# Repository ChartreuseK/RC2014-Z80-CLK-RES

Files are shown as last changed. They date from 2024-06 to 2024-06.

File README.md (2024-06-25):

## A z80 + Clock + Reset Board for the RC2014 Bus
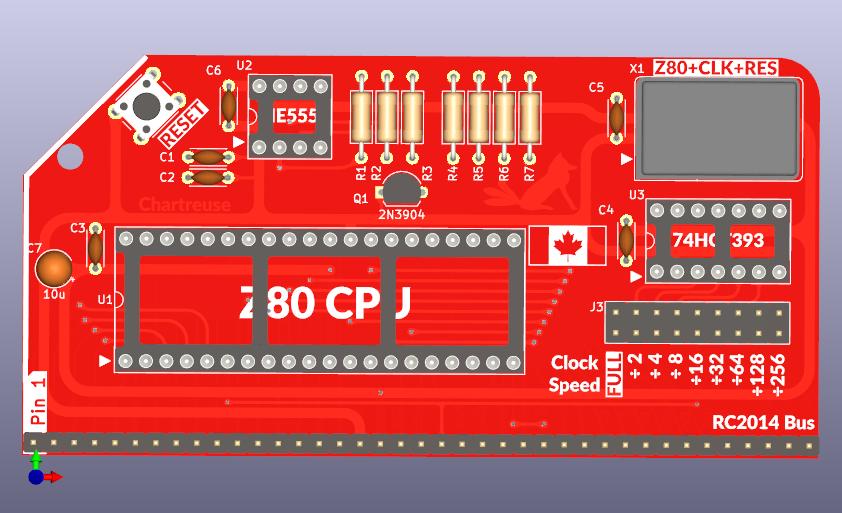
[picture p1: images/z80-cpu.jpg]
Revision 1 board front


A simple z80 board with integrated clock circuit (can oscillator) and divider. A 555 timer circuit provides power on and on demand reset with a clean pulse. 

The 74HCT393 is optional if you don't wish to divide the clock, just add a jumper or link on the FULL speed pad below it and it'll not be used. There is a shared footprint for either DIP-14 or DIP-8 can oscillators. For DIP-8 align it to the right edge of the socket. The reset pulse length can be shortened by lowering the values of R1 and R2, or adjusting the capacitor values. The 10k value of the pullup resistors is also nominal, and will likely work fine from 1k to 10k

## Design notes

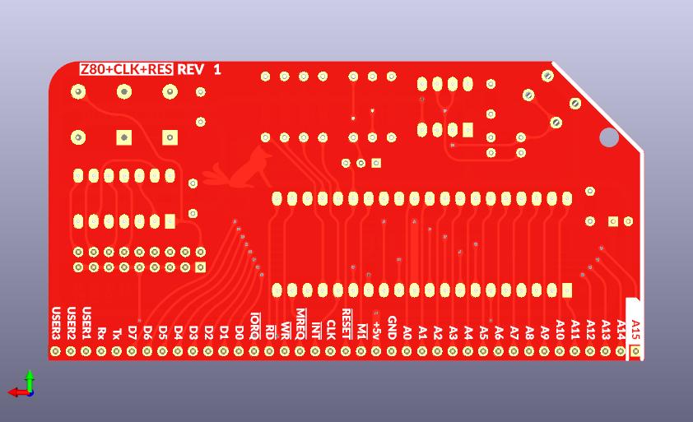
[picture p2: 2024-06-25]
images/z80-cpu-back.jpg

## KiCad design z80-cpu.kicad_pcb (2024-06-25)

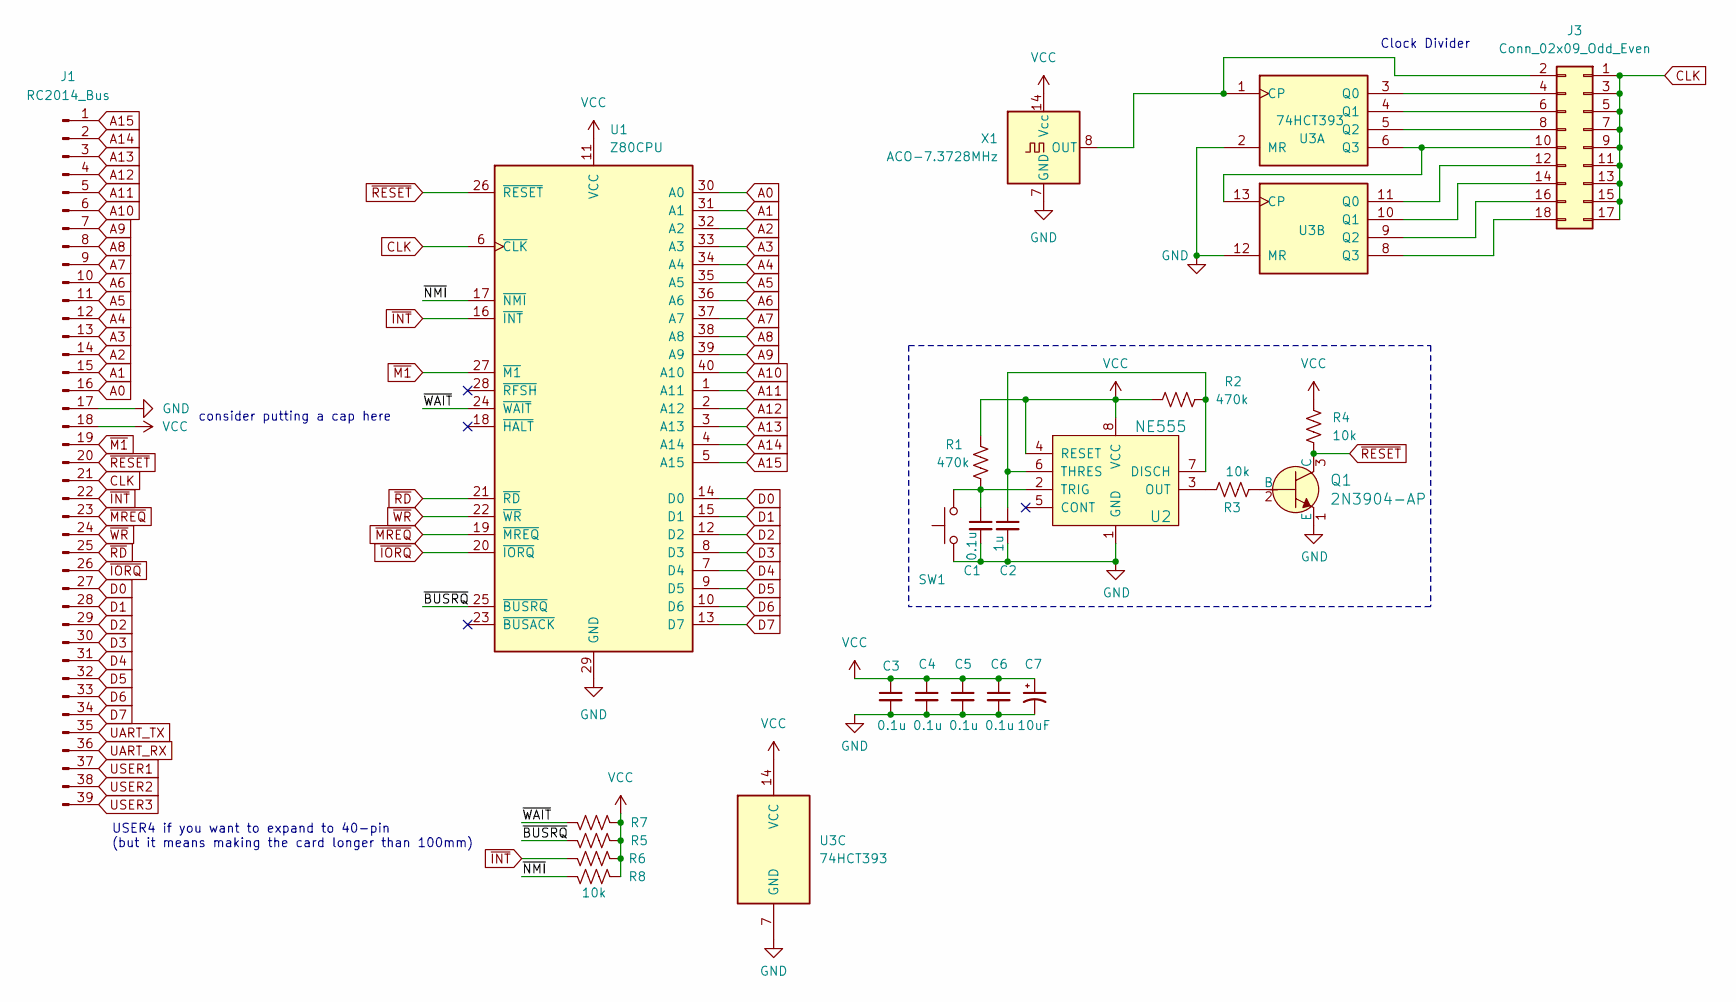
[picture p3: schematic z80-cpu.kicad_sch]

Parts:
C1, C3, C4, C5, C6: 0.1u; C_Disc_D4.3mm_W1.9mm_P5.00mm
C2: 1u; C_Disc_D4.3mm_W1.9mm_P5.00mm
C7: 10uF; CP_Radial_Tantal_D4.5mm_P2.50mm
J1: RC2014_Bus; PinHeader_1x39_P2.54mm_Vertical
J3: Conn_02x09_Odd_Even; PinHeader_2x09_P2.54mm_Vertical
Q1: 2N3904-AP; TO-92L_Inline_Wide; MPN 2N3904-AP; Digi-Key_PN 2N3904-APCT-ND
R1, R2: 470k; R_Axial_DIN0207_L6.3mm_D2.5mm_P10.16mm_Horizontal
R3, R4, R5, R6, R7, R8: 10k; R_Axial_DIN0207_L6.3mm_D2.5mm_P10.16mm_Horizontal
SW1: RESET; SW_PUSH_6mm
U1: Z80CPU; DIP-40_W15.24mm_Socket_LongPads
U2: NE555; DIP-8_W7.62mm_Socket_LongPads; MPN NE555P; Digi-Key_PN 296-1411-5-ND
U3: 74HCT393; DIP-14_W7.62mm_Socket_LongPads
X1: ACO-7.3728MHz; Oscillator_DIP-14_LargePads

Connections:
/~BUSRQ: R5.2, U1.25 (~BUSRQ)
/~NMI: R8.2, U1.17 (~NMI)
/~WAIT: R7.2, U1.24 (~WAIT)
A0: J1.16, U1.30 (A0)
A1: J1.15, U1.31 (A1)
A2: J1.14, U1.32 (A2)
A3: J1.13, U1.33 (A3)
A4: J1.12, U1.34 (A4)
A5: J1.11, U1.35 (A5)
A6: J1.10, U1.36 (A6)
A7: J1.9, U1.37 (A7)
A8: J1.8, U1.38 (A8)
A9: J1.7, U1.39 (A9)
A10: J1.6, U1.40 (A10)
A11: J1.5, U1.1 (A11)
A12: J1.4, U1.2 (A12)
A13: J1.3, U1.3 (A13)
A14: J1.2, U1.4 (A14)
A15: J1.1, U1.5 (A15)
CLK: J1.21, J3.1, J3.3, J3.5, J3.7, J3.9, J3.11, J3.13, J3.15, J3.17, U1.6 (~CLK)
D0: J1.27, U1.14 (D0)
D1: J1.28, U1.15 (D1)
D2: J1.29, U1.12 (D2)
D3: J1.30, U1.8 (D3)
D4: J1.31, U1.7 (D4)
D5: J1.32, U1.9 (D5)
D6: J1.33, U1.10 (D6)
D7: J1.34, U1.13 (D7)
GND: C1.2, C2.2, C3.2, C4.2, C5.2, C6.2, C7.2, J1.17, Q1.1 (E), SW1.1, U1.29 (GND), U2.1 (GND), U3.2 (MR), U3.7 (GND), U3.12 (MR), X1.7 (GND)
unnamed: J3.2, U3.1 (CP), X1.8 (OUT)
unnamed: J3.4, U3.3 (Q0)
unnamed: J3.6, U3.4 (Q1)
unnamed: J3.8, U3.5 (Q2)
unnamed: J3.10, U3.6 (Q3), U3.13 (CP)
unnamed: J3.12, U3.11 (Q0)
unnamed: J3.14, U3.10 (Q1)
unnamed: J3.16, U3.9 (Q2)
unnamed: J3.18, U3.8 (Q3)
unnamed: Q1.2 (B), R3.2
unnamed: C2.1, R2.1, U2.6 (THRES), U2.7 (DISCH)
unnamed: R3.1, U2.3 (OUT)
unnamed: C1.1, R1.2, SW1.2, U2.2 (TRIG)
UART_RX: J1.36
UART_TX: J1.35
USER1: J1.37
USER2: J1.38
USER3: J1.39
VCC: C3.1, C4.1, C5.1, C6.1, C7.1, J1.18, R1.1, R2.2, R4.1, R5.1, R6.1, R7.1, R8.1, U1.11 (VCC), U2.4 (RESET), U2.8 (VCC), U3.14 (VCC), X1.14 (Vcc)
~INT: J1.22, R6.2, U1.16 (~INT)
~IORQ: J1.26, U1.20 (~IORQ)
~M1: J1.19, U1.27 (~M1)
~MREQ: J1.23, U1.19 (~MREQ)
~RD: J1.25, U1.21 (~RD)
~RESET: J1.20, Q1.3 (C), R4.2, U1.26 (~RESET)
~WR: J1.24, U1.22 (~WR)

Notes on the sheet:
Clock Divider
consider putting a cap here
USER4 if you want to expand to 40-pin (but it means making the card longer than 100mm)

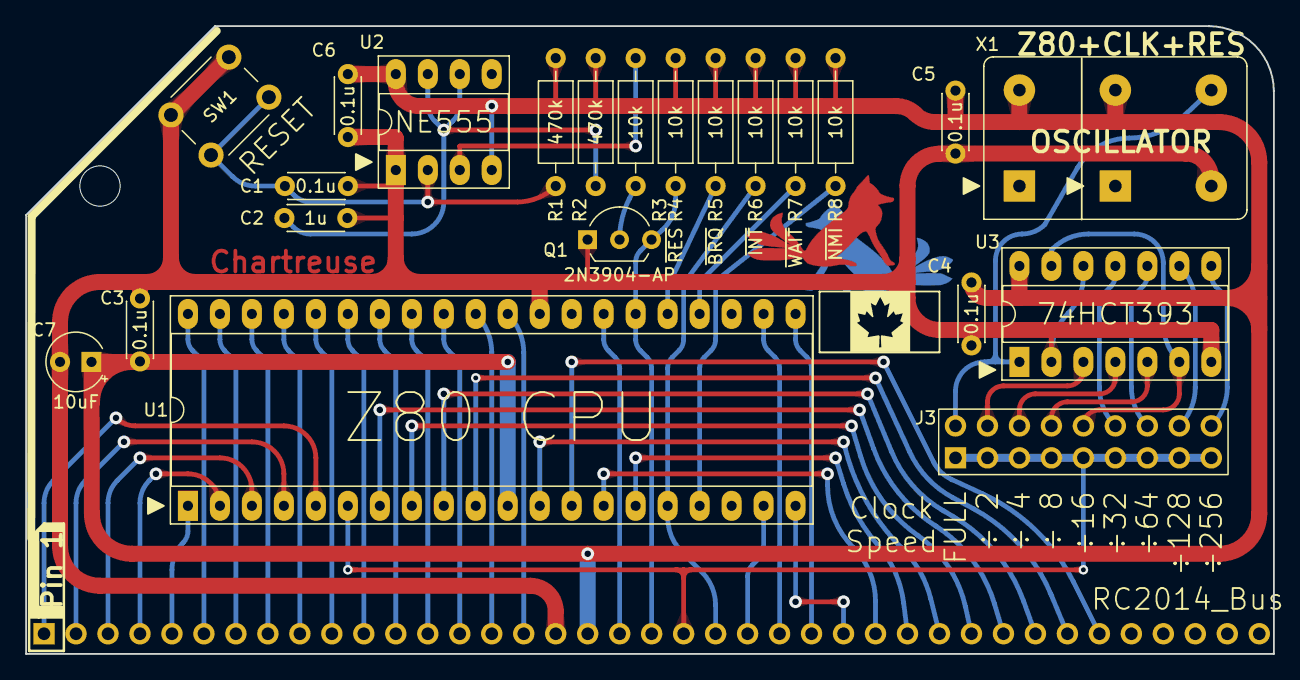
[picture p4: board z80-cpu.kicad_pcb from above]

Board: 2 copper layers, 99.1 x 49.9 mm, 23 parts (0 on the bottom side), 50 nets.

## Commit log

2024-06-25 Initial commit, simple z80 sbc with onboard clock generator and reset circuitry for rc2014
    [z80-cpu-B_Cu.gbl, z80-cpu-B_Mask.gbs, z80-cpu-B_Paste.gbp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]
2024-06-25 Changed bus labels to global labels, made uppercase
    [z80-cpu.kicad_sch]
2024-06-25 Added board images
2024-06-25 Fixed missing reset pullup, and slightly broken schematic after changing header labels. Rev 2
    [z80-cpu-B_Cu.gbl, z80-cpu-B_Mask.gbs, z80-cpu-B_Paste.gbp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]
